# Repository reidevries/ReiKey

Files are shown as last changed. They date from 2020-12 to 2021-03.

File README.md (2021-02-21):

# ReiKey
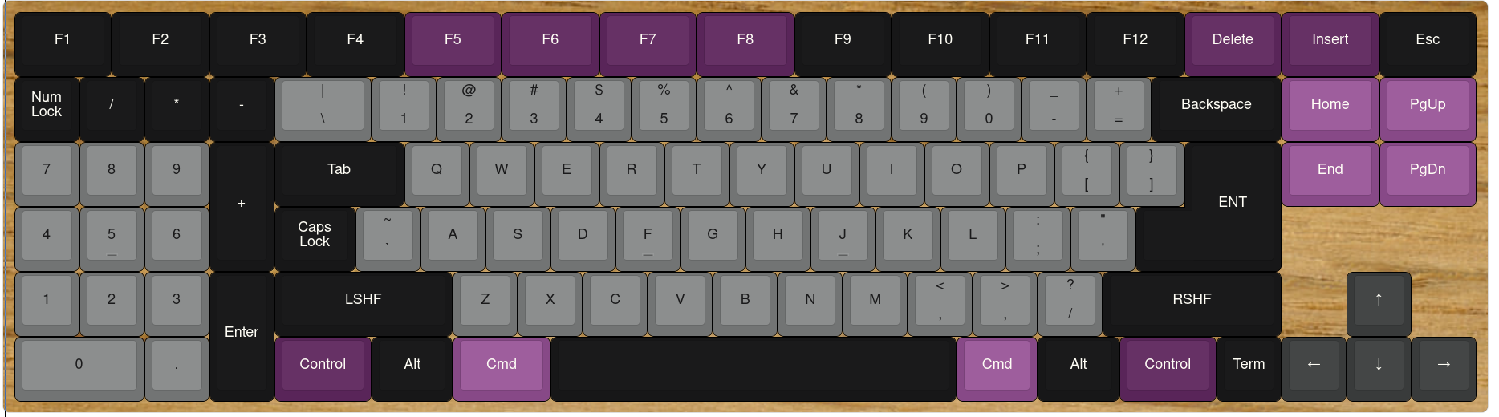
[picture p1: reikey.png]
DIY Keyboard custom design


This is a 101-key plateless PCB-based mechanical keyboard inspired by [JayK](https://github.com/josuegaleas/JayK) and [ONO-SENDAI MATRIX 83](https://imgur.com/a/v5pzh#FiXKcm0) as well as the Amiga 500 keyboard layout.

## Layout:
I went in the opposite route of most modern mechanical keyboards and used larger-size keys without any layers or "function" key. It is organised roughly into four sections - the numpad on the left, the alphanumeric keys in the middle, and navigation keys on the right, with a function key row on the top.

The numpad is on the left to improve ergonomics for data entry. The mouse is a kind of navigation function, so with the mouse on the right, the navigation keys and mouse are clustered together instead of having a numpad between them. In an IBM style layout, I would have to swap hands a lot to switch between the arrow keys and mouse while entering data with the numpad.

The top row and navigation keys are all 1.5U - inspired by the Amiga 500 keyboard which has larger function and delete keys. They are a bit easier to hit as a result. The escape key being on the far right might seem strange, but I really prefer it after using it for a while. The placement of insert and escape keys is really excellent for use with Vim keybindings - I can use insert to enter insert mode and the escape key right next to it to get back to normal mode. I removed the scroll lock and pause/break keys because I have never used them in my life. I removed the printscreen key because it seems superfluous to have a special key for such a specific function, instead I have a keycombo to capture screenshots in my window manager.

The alphanumeric keys are mostly similar to an IBM keyboard, however I opted for the "bigass" enter key because it just feels so good to hit. Instead of a tiny backspace key, I have a regular-size backspace. I rearranged the grave and backslash keys to make room, shrinking the capslock key which I almost never use. Inspired by Unix and Amiga keyboards, the whole left modifier section is extended. This means both shift keys are a full 2.75U. The 2U tab is great for programming where tab is used very regularly.
 
There is an extra key to the left of the left arrow key, which I am using to open an application launcher. You could also map it as a function key if you want some of the missing keys or media controls or something.
 
## Hardware Design:
The PCB is intended to be sandwiched between two pieces of wood, a top one with a cutout in the middle for all the keys, and a bottom one with a cutout for the Teensy LC. If a harder material than wood is used, you might need to make space for the pins of the switches and the SMD resistors. Softer materials don't have this requirement because the switch pins can stab into them a bit without issue. Eight M3 screws hold the pieces together. I chose a plateless design for simplicity and to reduce parts count.

## Electronic Design:
It uses a Teensy LC as the microcontroller. I chose this because it is very small and low cost.
It has a 10x10 keyboard matrix with the delete key going directly to ground. The only LEDs are under the caps lock and num lock keys, and a power LED above the arrow keys. I would recommend using 470 ohm resistors for the caps and num lock LEDs and a higher value resistor like 1.5k ohm for the power LED as the power LED is constantly on and can get annoying if it's too bright.

## Finding keycaps:
I succesfully built this keyboard and have been using it as my daily driver for several months now. The most difficult part was finding keycaps for the unusual layout. First, I ordered a full DSA keycap set which had a "bigass" enter key included; it was quite difficult to find this type of enter key in DSA. Then I ordered about 24 blank 1.5U keys in colours that complemented the initial keycap set, and 4 blank 2.75U keys for the dual 2.75U shifts. Then for the Tab and Command keys, I ordered some custom-printed individual DSA keycaps from signature plastics for 5 dollars each. I was easily able to find a key with an LED hole for the numlock key, but I still haven't found one suitable for the 1.25U capslock. I would highly recommend using DSA keycaps as it has the same profile for every row, unlike all other key profiles like DCS, OEM, SA etc. 

If you want to custom-design a keycap set to fit this keyboard, you will need to include at least:
* "bigass" enter key
* 2U Tab
* 1.25U caps lock, preferrably with some way for the LED to shine through it.
* Dual 2.75U shift keys
* Dual 1.5U control keys
* One 1.5U command key and one 1.25U command key

It's relatively easy to find 1.5U blanks so I'd consider them less important to include as they will add a lot of cost to a regular keycap set. But if you want, the required 1.5U keys include F1 to F12, Delete, Insert, Escape, Page Up, Page Down, Home, and End

## PCB:
The PCB is made in Kicad and requires [keebs.pretty](https://github.com/egladman/keebs.pretty) for the keyboard footprints. I had to make a custom footprint for the ""bigass"" enter key.
It also requires the teensy [symbol](https://github.com/XenGi/teensy_library) and [footprint](https://github.com/XenGi/teensy.pretty) libraries from github user XenGi.
The PCB still has an older layout written on the silkscreen.

## Programming:
I used C with the Teensy/Arduino keyboard libraries to register keypresses and send them to a computer. Thanks to @cruxic for the [Teensy makefile](https://github.com/cruxic/teensy-makefile). It has a delay of ~150us between checking each column to avoid duplicate keypresses. Simply build the board, plug in the Teensy LC via usb, install Teensy/arduino libraries correctly, then type `make load` and you should get a working keyboard. NOTE: You may need to edit the ROWS or COLS in main.c to get the layout working for your keyboard. I burnt some pins on my teensy and remapped.

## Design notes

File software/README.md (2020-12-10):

#(This readme is taken from another repository! see the main README.md in the project root folder)
This Makefile compiles C/C++ code for a Teensy-LC USB development board without the Arduino IDE.

## Setup
The simplest way to get the latest Teensy compiler and core libraries is to install Arduino IDE and [the Teensyduino plugin](https://www.pjrc.com/teensy/td_download.html).  You will not be using the IDE, just the plugin.

Next, fix the three symlinks in ./Compiler.  They should point to:
  1. arm-bin -> /path/to/your/arduino-ide/hardware/tools/arm/bin/
  2. teensy3 -> /path/to/your/arduino-ide/hardware/teensy/avr/cores/teensy3
  3. teensy-tools -> /path/to/your/arduino-ide/hardware/tools

## Usage

To compile `program.hex`:

```bash
make
```
*Note: the first time this is run, it also compiles all the core teensy sources into teensy3.a*

Or, to compile and automatically launch the Teensy Loader:
```bash
make load
```

To clean all compiled files:
```bash
make clean
```

## Background
Finding the magical combination of programs and flags to create a working hex file was a very frustrating process.  The Makefile provided by PJRC (arduino/hardware/teensy/avr/cores/teensy3/Makefile) did not work for me because the linkage step silently ignored any undefined references.  The linker worked as it should when compiling from Arduino IDE.  So I set `build.verbose=true` in `~/.arduino15/preferences.txt` and was able to observe the exact compiling commands and create this Makefile.

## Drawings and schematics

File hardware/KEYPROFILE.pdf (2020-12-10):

## top view

## side view

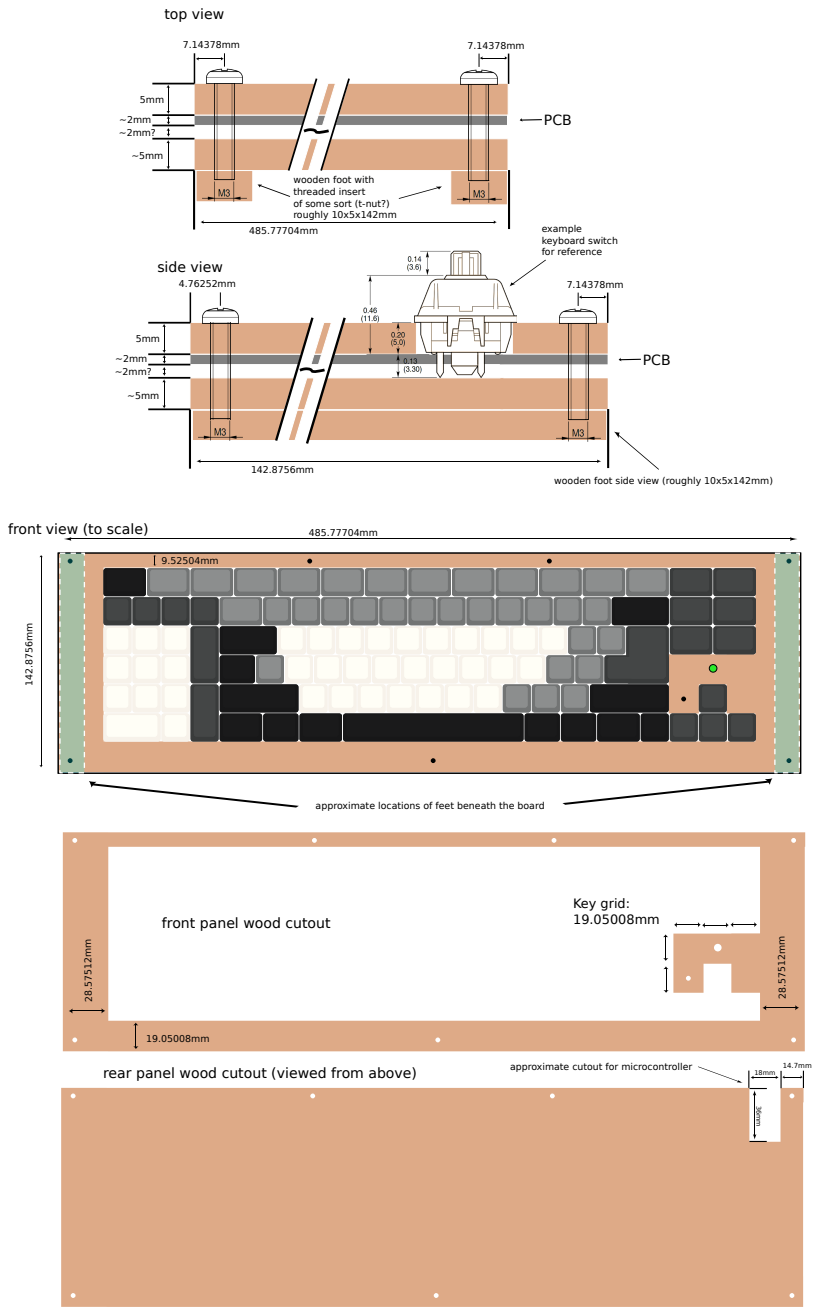
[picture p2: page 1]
example keyboard switch for reference; PCB; Key grid: 19.05008mm; rear panel wood cutout (viewed from above)

wooden foot with
threaded insert
of some sort (t-nut?)
roughly 10x5x142mm

wooden foot side view (roughly 10x5x142mm)

front view (to scale)

approximate locations of feet beneath the board

front panel wood cutout

approximate cutout for microcontroller

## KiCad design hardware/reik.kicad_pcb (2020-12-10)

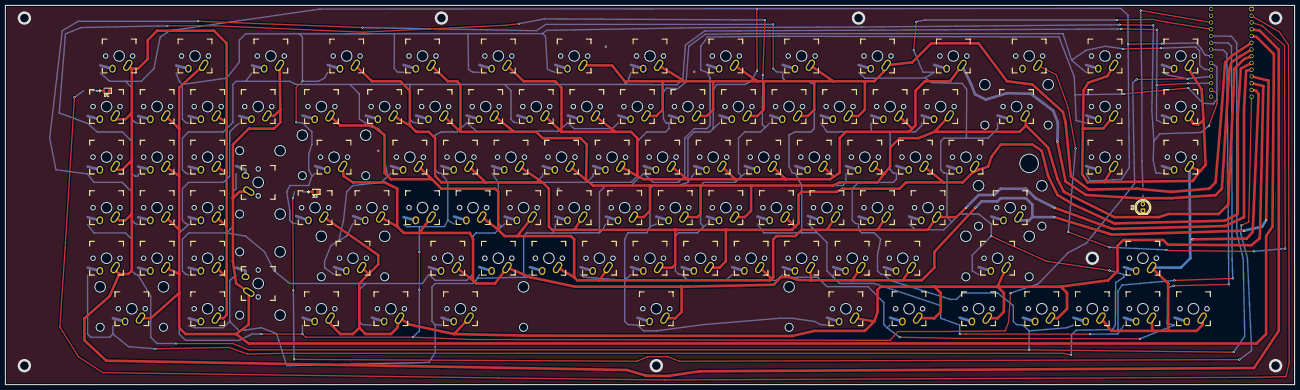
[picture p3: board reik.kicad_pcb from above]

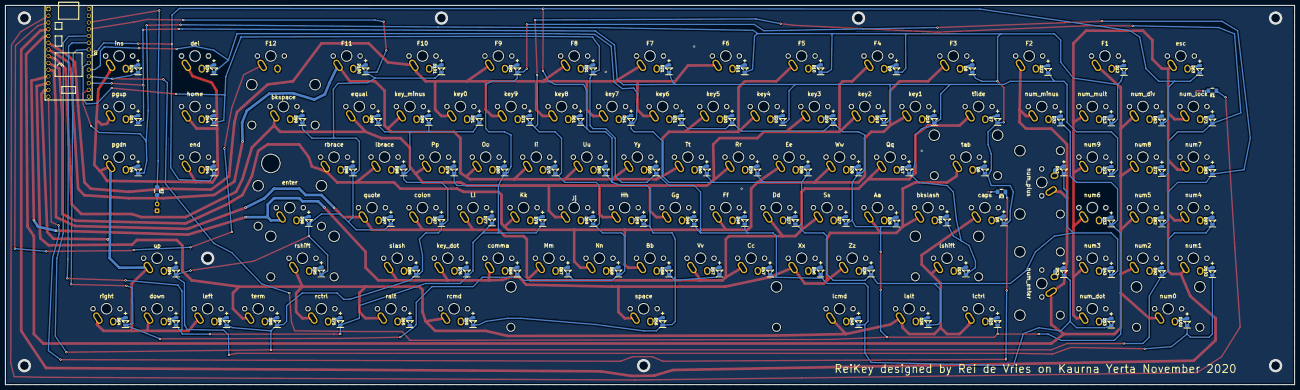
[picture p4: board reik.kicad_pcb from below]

Board: 2 copper layers, 485.8 x 142.9 mm, 208 parts (104 on the bottom side), 128 nets.

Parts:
D1: num_led; LED0805_handsolder
D2: pwr_led; LED_D5.0mm
D3: caps_led; LED0805_handsolder
D4, D5, D6, D7, D8, D9, D10, D11, D12, D13, D14, D15, D16, D17, D18, D19, D20, D21, D22, D23, D24, D25, D26, D27, D28, D29, D30, D31, D32, D33, D34, D35, D36, D37, D38, D39, D40, D41, D42, D43, D44, D45, D46, D47, D48, D49, D50, D51, D52, D53, D54, D55, D56, D57, D58, D59, D60, D61, D62, D63, D64, D65, D66, D67, D68, D69, D70, D71, D72, D73, D74, D75, D76, D77, D78, D79, D80, D81, D82, D83, D84, D85, D86, D87, D88, D89, D90, D91, D92, D93, D94, D95, D96, D97, D98, D99, D100, D101, D102, D103: D_Small_ALT; D1206
R1, R3: 330; R_1206_3216Metric_Pad1.42x1.75mm_HandSolder
R2: 1k; R_1206_3216Metric_Pad1.42x1.75mm_HandSolder
SW1: pgdn; Mx_Alps_150
SW2: caps; Mx_Alps_125
SW3: tab; Mx_Alps_200
SW4: tilde; Mx_Alps_150
SW5: F3; Mx_Alps_150
SW6: F4; Mx_Alps_150
SW7: F5; Mx_Alps_150
SW8: F6; Mx_Alps_150
SW9: F1; Mx_Alps_150
SW10: num_mult; Mx_Alps_100
SW11: F12; Mx_Alps_150
SW12: pgup; Mx_Alps_150
SW13: lshift; Mx_Alps_275
SW14: bkslash; Mx_Alps_100
SW15: Qq; Mx_Alps_100
SW16: key1; Mx_Alps_100
SW17: key2; Mx_Alps_100
SW18: key4; Mx_Alps_100
SW19: F7; Mx_Alps_150
SW20: F2; Mx_Alps_150
SW21: num9; Mx_Alps_100
SW22: ins; Mx_Alps_150
SW23: lctrl; Mx_Alps_150
SW24: Aa; Mx_Alps_100
SW25: Ss; Mx_Alps_100
SW26: Ww; Mx_Alps_100
SW27: key3; Mx_Alps_100
SW28: key5; Mx_Alps_100
SW29: key6; Mx_Alps_100
SW30: num_minus; Mx_Alps_100
SW31: num6; Mx_Alps_100
SW32: del; Mx_Alps_150
SW33: lalt; Mx_Alps_125
SW34: Zz; Mx_Alps_100
SW35: Dd; Mx_Alps_100
SW36: Ee; Mx_Alps_100
SW37: Rr; Mx_Alps_100
SW38: Tt; Mx_Alps_100
SW39: key7; Mx_Alps_100
SW40: num_plus; Mx_Alps_200
SW41: num3; Mx_Alps_100
SW42: home; Mx_Alps_150
SW43: lcmd; Mx_Alps_150
SW44: Xx; Mx_Alps_100
SW45: Cc; Mx_Alps_100
SW46: Ff; Mx_Alps_100
SW47: Gg; Mx_Alps_100
SW48: Yy; Mx_Alps_100
SW49: F8; Mx_Alps_150
SW50: num_enter; Mx_Alps_200
SW51: num_dot; Mx_Alps_100
SW52: end; Mx_Alps_150
SW53: rcmd; Mx_Alps_125
SW54: space; Mx_Alps_625
SW55: Vv; Mx_Alps_100
SW56: Bb; Mx_Alps_100
SW57: Hh; Mx_Alps_100
SW58: Uu; Mx_Alps_100
SW59: key8; Mx_Alps_100
SW60: num_div; Mx_Alps_100
SW61: esc; Mx_Alps_150
SW62: right; Mx_Alps_100
SW63: ralt; Mx_Alps_125
SW64: comma; Mx_Alps_100
SW65: Mm; Mx_Alps_100
SW66: Nn; Mx_Alps_100
SW67: Jj; Mx_Alps_100
SW68: Ii; Mx_Alps_100
SW69: key9; Mx_Alps_100
SW70: num8; Mx_Alps_100
SW71: num_lock; Mx_Alps_100
SW72: down; Mx_Alps_100
SW73: rctrl; Mx_Alps_150
SW74: key_dot; Mx_Alps_100
SW75: Ll; Mx_Alps_100
SW76: Kk; Mx_Alps_100
SW77: Pp; Mx_Alps_100
SW78: Oo; Mx_Alps_100
SW79: F9; Mx_Alps_150
SW80: num5; Mx_Alps_100
SW81: num7; Mx_Alps_100
SW82: left; Mx_Alps_100
SW83: term; Mx_Alps_100
SW84: slash; Mx_Alps_100
SW85: colon; Mx_Alps_100
SW86: lbrace; Mx_Alps_100
SW87: equal; Mx_Alps_100
SW88: key_minus; Mx_Alps_100
SW89: key0; Mx_Alps_100
SW90: num2; Mx_Alps_100
SW91: num4; Mx_Alps_100
SW92: up; Mx_Alps_100
SW93: rshift; Mx_Alps_275
SW94: enter; Mx_Alps_BigEnter
SW95: quote; Mx_Alps_100
SW96: rbrace; Mx_Alps_100
SW97: bkspace; Mx_Alps_200
SW98: F11; Mx_Alps_150
SW99: F10; Mx_Alps_150
SW100: num0; Mx_Alps_200
SW101: num1; Mx_Alps_100
U1: Teensy-LC; TeensyLC_outer

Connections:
/Matrix/col01: D4.1, D5.1, D6.1, D7.1, D8.1, D9.1, D10.1, D11.1, D12.1, D13.1, U1.21
/Matrix/col02: D14.1, D15.1, D16.1, D17.1, D18.1, D19.1, D20.1, D21.1, D22.1, D23.1, U1.22
/Matrix/col03: D24.1, D25.1, D26.1, D27.1, D28.1, D29.1, D30.1, D31.1, D32.1, D33.1, U1.23
/Matrix/col04: D34.1, D35.1, D36.1, D37.1, D38.1, D39.1, D40.1, D41.1, D42.1, D43.1, U1.24
/Matrix/col05: D44.1, D45.1, D46.1, D47.1, D48.1, D49.1, D50.1, D51.1, D52.1, D53.1, U1.25
/Matrix/col06: D54.1, D55.1, D56.1, D57.1, D58.1, D59.1, D60.1, D61.1, D62.1, D63.1, U1.26
/Matrix/col07: D64.1, D65.1, D66.1, D67.1, D68.1, D69.1, D70.1, D71.1, D72.1, D73.1, U1.27
/Matrix/col08: D74.1, D75.1, D76.1, D77.1, D78.1, D79.1, D80.1, D81.1, D82.1, D83.1, U1.28
/Matrix/col09: D84.1, D85.1, D86.1, D87.1, D88.1, D89.1, D90.1, D91.1, D92.1, D93.1, U1.29
/Matrix/col10: D94.1, D95.1, D96.1, D97.1, D98.1, D99.1, D100.1, D101.1, D102.1, D103.1, U1.30
/Matrix/row01: SW1.1, SW12.1, SW22.1, SW32.1, SW42.1, SW52.1, SW62.1, SW72.1, SW82.1, SW92.1, U1.13
/Matrix/row02: SW2.1, SW13.1, SW23.1, SW33.1, SW43.1, SW53.1, SW63.1, SW73.1, SW83.1, SW93.1, U1.12
/Matrix/row03: SW3.1, SW14.1, SW24.1, SW34.1, SW44.1, SW54.1, SW64.1, SW74.1, SW84.1, SW94.1, U1.11
/Matrix/row04: SW4.1, SW15.1, SW25.1, SW35.1, SW45.1, SW55.1, SW65.1, SW75.1, SW85.1, SW95.1, U1.10
/Matrix/row05: SW5.1, SW16.1, SW26.1, SW36.1, SW46.1, SW56.1, SW66.1, SW76.1, SW86.1, SW96.1, U1.9
/Matrix/row06: SW6.1, SW17.1, SW27.1, SW37.1, SW47.1, SW57.1, SW67.1, SW77.1, SW87.1, SW97.1, U1.8
/Matrix/row07: SW7.1, SW18.1, SW28.1, SW38.1, SW48.1, SW58.1, SW68.1, SW78.1, SW88.1, SW98.1, U1.7
/Matrix/row08: SW8.1, SW19.1, SW29.1, SW39.1, SW49.1, SW59.1, SW69.1, SW79.1, SW89.1, SW99.1, U1.6
/Matrix/row09: SW9.1, SW20.1, SW30.1, SW40.1, SW50.1, SW60.1, SW70.1, SW80.1, SW90.1, SW100.1, U1.5
/Matrix/row10: SW10.1, SW21.1, SW31.1, SW41.1, SW51.1, SW61.1, SW71.1, SW81.1, SW91.1, SW101.1, U1.4
/Matrix/row11: SW11.1, U1.3
GND: D1.1, D2.1, D3.1, SW11.2, U1.1, U1.32
unnamed: D1.2, R1.2
unnamed: D2.2, R2.2
unnamed: D3.2, R3.2
unnamed: D4.2, SW1.2
unnamed: D5.2, SW2.2
unnamed: D6.2, SW3.2
unnamed: D7.2, SW4.2
unnamed: D8.2, SW5.2
unnamed: D9.2, SW6.2
unnamed: D10.2, SW7.2
unnamed: D11.2, SW8.2
unnamed: D12.2, SW9.2
unnamed: D13.2, SW10.2
unnamed: D14.2, SW12.2
unnamed: D15.2, SW13.2
unnamed: D16.2, SW14.2
unnamed: D17.2, SW15.2
unnamed: D18.2, SW16.2
unnamed: D19.2, SW17.2
unnamed: D20.2, SW18.2
unnamed: D21.2, SW19.2
unnamed: D22.2, SW20.2
unnamed: D23.2, SW21.2
unnamed: D24.2, SW22.2
unnamed: D25.2, SW23.2
unnamed: D26.2, SW24.2
unnamed: D27.2, SW25.2
unnamed: D28.2, SW26.2
unnamed: D29.2, SW27.2
unnamed: D30.2, SW28.2
unnamed: D31.2, SW29.2
unnamed: D32.2, SW30.2
unnamed: D33.2, SW31.2
unnamed: D34.2, SW32.2
unnamed: D35.2, SW33.2
unnamed: D36.2, SW34.2
unnamed: D37.2, SW35.2
unnamed: D38.2, SW36.2
unnamed: D39.2, SW37.2
unnamed: D40.2, SW38.2
unnamed: D41.2, SW39.2
unnamed: D42.2, SW40.2
unnamed: D43.2, SW41.2
unnamed: D44.2, SW42.2
unnamed: D45.2, SW43.2
unnamed: D46.2, SW44.2
unnamed: D47.2, SW45.2
unnamed: D48.2, SW46.2
unnamed: D49.2, SW47.2
unnamed: D50.2, SW48.2
unnamed: D51.2, SW49.2
unnamed: D52.2, SW50.2
unnamed: D53.2, SW51.2
unnamed: D54.2, SW52.2
unnamed: D55.2, SW53.2
unnamed: D56.2, SW54.2
unnamed: D57.2, SW55.2
unnamed: D58.2, SW56.2
unnamed: D59.2, SW57.2
unnamed: D60.2, SW58.2
unnamed: D61.2, SW59.2
unnamed: D62.2, SW60.2
unnamed: D63.2, SW61.2
unnamed: D64.2, SW62.2
unnamed: D65.2, SW63.2
unnamed: D66.2, SW64.2
unnamed: D67.2, SW65.2
unnamed: D68.2, SW66.2
unnamed: D69.2, SW67.2
unnamed: D70.2, SW68.2
unnamed: D71.2, SW69.2
unnamed: D72.2, SW70.2
unnamed: D73.2, SW71.2
unnamed: D74.2, SW72.2
unnamed: D75.2, SW73.2
unnamed: D76.2, SW74.2
unnamed: D77.2, SW75.2
unnamed: D78.2, SW76.2
unnamed: D79.2, SW77.2
unnamed: D80.2, SW78.2
unnamed: D81.2, SW79.2
unnamed: D82.2, SW80.2
unnamed: D83.2, SW81.2
unnamed: D84.2, SW82.2
unnamed: D85.2, SW83.2
unnamed: D86.2, SW84.2
unnamed: D87.2, SW85.2
unnamed: D88.2, SW86.2
unnamed: D89.2, SW87.2
unnamed: D90.2, SW88.2
unnamed: D91.2, SW89.2
unnamed: D92.2, SW90.2
unnamed: D93.2, SW91.2
unnamed: D94.2, SW92.2
unnamed: D95.2, SW93.2
unnamed: D96.2, SW94.2
unnamed: D97.2, SW95.2
unnamed: D98.2, SW96.2
unnamed: D99.2, SW97.2
unnamed: D100.2, SW98.2
unnamed: D101.2, SW99.2
unnamed: D102.2, SW100.2
unnamed: D103.2, SW101.2
unnamed: R1.1, U1.2
unnamed: R2.1, U1.31
unnamed: R3.1, U1.14

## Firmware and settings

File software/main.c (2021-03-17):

#include "WProgram.h"
#include <usb_keyboard.h>
#include "pin_assignment.h"

#define KEY_MENU                ( 101  | 0xF000 )
#define KEY_F13                 ( 104  | 0xF000 )
#define KEY_F14                 ( 105  | 0xF000 )
#define KEY_F15                 ( 106  | 0xF000 )
#define KEY_F16                 ( 107  | 0xF000 )
#define KEY_F17                 ( 108  | 0xF000 )
#define KEY_F18                 ( 109  | 0xF000 )
#define KEY_F19                 ( 110  | 0xF000 )
#define KEY_F20                 ( 111  | 0xF000 )
#define KEY_F21                 ( 112  | 0xF000 )
#define KEY_F22                 ( 113  | 0xF000 )
#define KEY_F23                 ( 114  | 0xF000 )
#define KEY_F24                 ( 115  | 0xF000 )

//checks if a button on a given pin has been pressed or released
#define PRESSED 2
#define RELEASED 1
int held[10][10] = {
  { 0, 0, 0, 0, 0, 0, 0, 0, 0, 0},
  { 0, 0, 0, 0, 0, 0, 0, 0, 0, 0},
  { 0, 0, 0, 0, 0, 0, 0, 0, 0, 0},
  { 0, 0, 0, 0, 0, 0, 0, 0, 0, 0},
  { 0, 0, 0, 0, 0, 0, 0, 0, 0, 0},
  { 0, 0, 0, 0, 0, 0, 0, 0, 0, 0},
  { 0, 0, 0, 0, 0, 0, 0, 0, 0, 0},
  { 0, 0, 0, 0, 0, 0, 0, 0, 0, 0},
  { 0, 0, 0, 0, 0, 0, 0, 0, 0, 0},
  { 0, 0, 0, 0, 0, 0, 0, 0, 0, 0}
};
int held_R11 = 0;

uint8_t checkPin(const int pin, int* const held)
{
	int val = digitalRead(pin);
	if (val == LOW && *held == 0) {
		*held = 1;
		return PRESSED;
	} else if (val == HIGH && *held == 1) {
		*held = 0;
		return RELEASED;
	}
	return 0;
}

//checks if a button at a given row and column in the key matrix has been
//pressed or released, and sends the matching keycode via usb
void checkKey(const int row, const int col)
{
	switch (checkPin(ROWS[row], &held[row][col])) {
	case PRESSED:
		usb_keyboard_press_keycode(key_matrix[row][col]);
		break;
	case RELEASED:
		usb_keyboard_release_keycode(key_matrix[row][col]);
		break;
	default: break;
	}
}

//sets a given column index to ground, and the rest to Hi-Z
void setupCol(const int col)
{
	for (int i = 0; i < col; ++i) {
		pinMode(COLS[i], INPUT);
	}
	pinMode(COLS[col], OUTPUT);
	digitalWrite(COLS[col], LOW);
	for (int i = col+1; i<10; ++i) {
		pinMode(COLS[i], INPUT);
	}
}

int main(void)
{	
	delay(1000); //make sure op sys has enough time to register input device
	// set up pins to the correct modes
	pinMode(NUM_LED, OUTPUT);
	pinMode(CAP_LED, OUTPUT);
	pinMode(PIN_R11, INPUT_PULLUP);
	for (int i = 0; i < 10; ++i) {
		pinMode(ROWS[i], INPUT_PULLUP);
	}
	// set the dead pins to be just inputs
	pinMode(10, INPUT);
	pinMode(11, INPUT);
	
	int col = 0;
	for (;;) {
		//update num/caps lock LED
		digitalWrite(NUM_LED, keyboard_leds&0x01);
		digitalWrite(CAP_LED, (keyboard_leds&0x02)>>1);
		
		//set up the current column
		setupCol(col);
		// delay to avoid retriggering and up arrow triggering page down
		delayMicroseconds(500);
	
		//check each row in the column for key presses
		for (int row = 0; row < 10; ++row) {
			checkKey(row, col);
		}

		//manually check row 11 as it is always grounded
		switch (checkPin(PIN_R11, &held_R11)) {
		case PRESSED:
			usb_keyboard_press_keycode(PIN_R11_KEY);
			break;
		case RELEASED:
			usb_keyboard_release_keycode(PIN_R11_KEY);
		default: break;
		}
		col = (col+1)%10;
	}
}

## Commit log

2020-12-10 add hardware files
    [matrix.sch, reik.kicad_pcb, reik.sch]
2020-12-10 remove hardware files from wrong place in file structure
    [matrix.sch, reik.kicad_pcb, reik.sch]
2021-03-17 put pin assignment in separate file for portability
2021-03-17 convert some if checks to switch statements
